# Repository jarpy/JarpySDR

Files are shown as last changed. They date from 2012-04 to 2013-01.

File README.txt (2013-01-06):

JarpySDR - A Tayloe Detector board for Software Defined Radio.

This is a simple SDR frontend using all through-hole components.

It requires an off-board square-wave oscillator/clock running at F*4, where F is the radio frequency to be recieved. The design is pin compatible with WA6UFQ's Si570 oscillator card, and provides an I2C pass-through header with which to program the Si570.

You don't have to use the Si570 board however. You can clock it with any square-wave source you have handy.

The design is derived from the G0NQE Acorn SDR receiver.

Links:
  Si570 oscillator board
  http://home.roadrunner.com/~wa6ufq/universal_vfo_controller.html

  G0NQE Acorn SDR
  http://www.g0nqe.co.uk/projects/g0nqe-acorn_sdr_receiver

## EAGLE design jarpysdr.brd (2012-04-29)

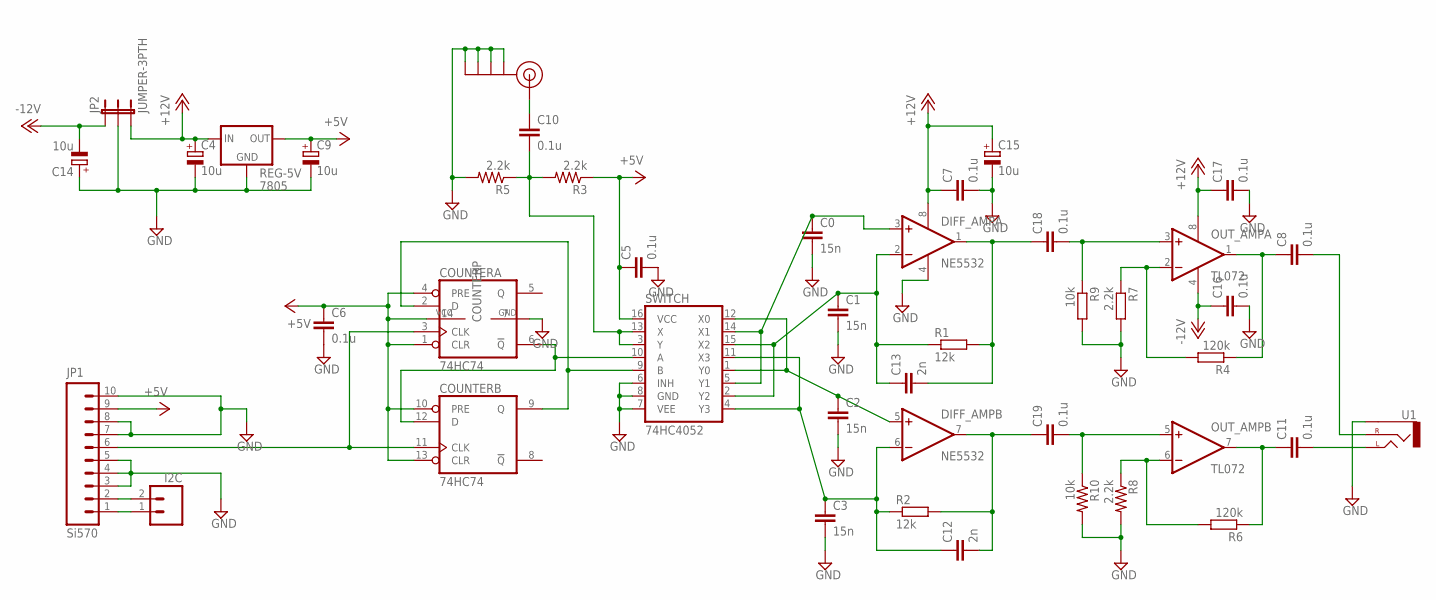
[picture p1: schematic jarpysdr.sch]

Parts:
ANTENNA: SMA_EDGE; SMA-EDGE
C0, C1, C2, C3: 15n; C025-024X044
C4, C9, C14, C15: 10u; E2,5-6
C5, C6, C7, C16, C17: 0.1u; C025-025X050
C8, C11, C18, C19: 0.1u; C050-025X075
C10: 0.1u; C025-024X044
C12, C13: 2n; C025-024X044
COUNTER: 74HC74; DIL14
DIFF_AMP: NE5532; DIL08
I2C: M02PTH; 1X02
JP1: Si570; 1X10
JP2: JUMPER-3PTH; 1X03
OUT_AMP: TL072; DIL08
R1, R2: 12k; 0204/7
R3, R5, R7, R8: 2.2k; 0204/7
R4, R6: 120k; 0204/7
R9, R10: 10k; 0204/7
REG-5V: 7805; 78XXS
SWITCH: 74HC4052; DIL16
U1: AUDIO-JACKPTH; AUDIO-JACK

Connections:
+5V: C5.1, C6.1, C9.+, COUNTER.1 (CLR), COUNTER.4 (PRE), COUNTER.10 (PRE), COUNTER.13 (CLR), COUNTER.14 (VCC), JP1.9, R3.1, REG-5V.OUT, SWITCH.16 (VCC)
+12V: C4.+, C7.1, C15.+, C17.1, DIFF_AMP.8 (V+), JP2.3, OUT_AMP.8 (V+), REG-5V.IN
-12V: C14.-, C16.1, JP2.1, OUT_AMP.4 (V-)
C-180DEG: C1.1, C13.1, DIFF_AMP.2 (-IN), R1.1, SWITCH.2 (Y2), SWITCH.15 (X2)
CLK: COUNTER.3 (CLK), COUNTER.11 (CLK), JP1.6
GND: ANTENNA.GND@0 (GND), ANTENNA.GND@1 (GND), ANTENNA.GND@2 (GND), ANTENNA.GND@3 (GND), C0.2, C1.2, C2.2, C3.2, C4.-, C5.2, C6.2, C7.2, C9.-, C14.+, C15.-, C16.2, C17.2, COUNTER.7 (GND), DIFF_AMP.4 (V-), JP1.3, JP1.4, JP1.5, JP1.7, JP1.8, JP1.10, JP2.2, R5.2, R7.2, R8.2, R9.2, R10.2, REG-5V.GND, SWITCH.6 (INH), SWITCH.7 (VEE), SWITCH.8 (GND), U1.SLEEVE
unnamed: C2.1, DIFF_AMP.5 (+IN), SWITCH.1 (Y0), SWITCH.12 (X0)
unnamed: COUNTER.2 (D), COUNTER.9 (Q), SWITCH.9 (B)
unnamed: COUNTER.6 (!Q), COUNTER.12 (D), SWITCH.10 (A)
unnamed: C10.2, R3.2, R5.1, SWITCH.3 (Y), SWITCH.13 (X)
unnamed: C0.1, DIFF_AMP.3 (+IN), SWITCH.5 (Y1), SWITCH.14 (X1)
unnamed: C13.2, C18.1, DIFF_AMP.1 (OUT), R1.2
unnamed: ANTENNA.SIG (SIGNAL), C10.1
unnamed: C11.2, U1.TIP (LEFT)
unnamed: C8.2, U1.RING (RIGHT)
unnamed: C12.2, C19.1, DIFF_AMP.7 (OUT), R2.2
unnamed: C8.1, OUT_AMP.1 (OUT), R4.1
unnamed: OUT_AMP.2 (-IN), R4.2, R7.1
unnamed: C11.1, OUT_AMP.7 (OUT), R6.1
unnamed: C3.1, C12.1, DIFF_AMP.6 (-IN), R2.1, SWITCH.4 (Y3), SWITCH.11 (X3)
unnamed: OUT_AMP.6 (-IN), R6.2, R8.1
unnamed: I2C.1, JP1.1
unnamed: I2C.2, JP1.2
unnamed: C18.2, OUT_AMP.3 (+IN), R9.1
unnamed: C19.2, OUT_AMP.5 (+IN), R10.1

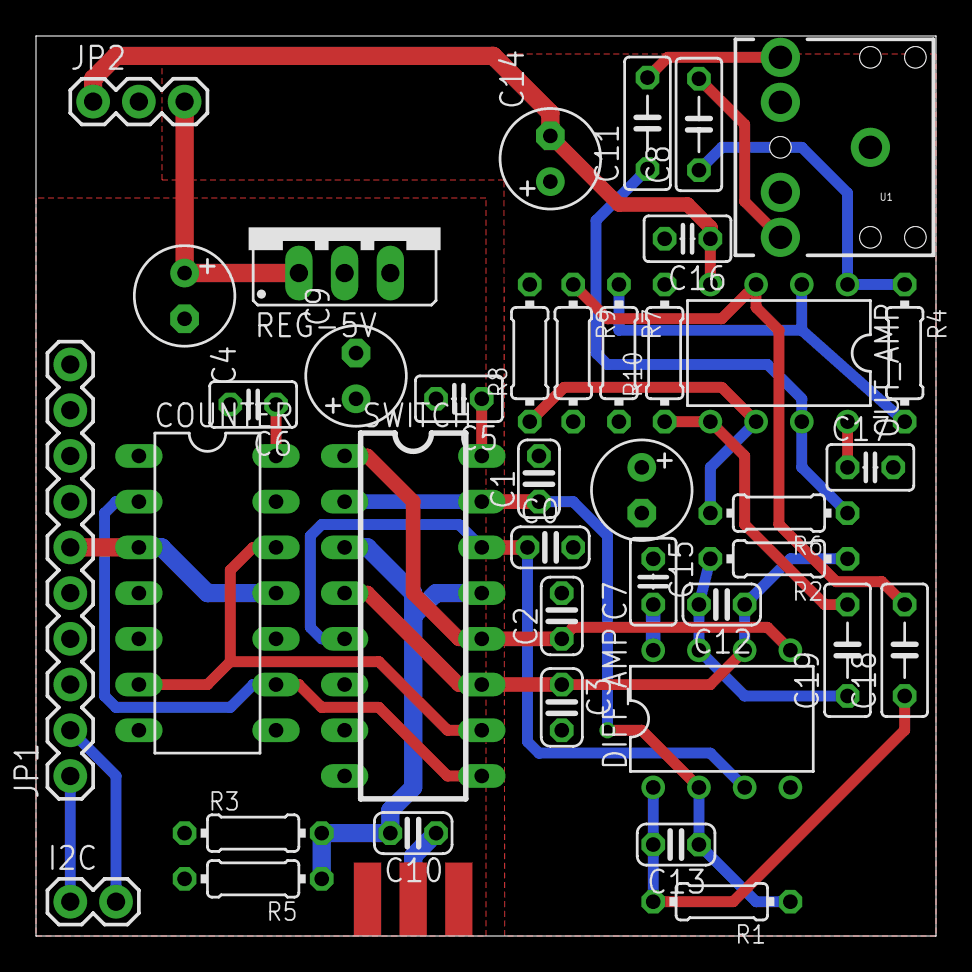
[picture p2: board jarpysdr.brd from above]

Board: 2 copper layers, 50.0 x 50.0 mm, 40 parts (0 on the bottom side), 25 nets.

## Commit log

2011-10-29 First prototype.
    [jarpysdr.brd, jarpysdr.sch]
2012-03-24 - Replace with audio and antenna connectors with jacks available from SparkFun.
    - Make room for a heatsink on the 7805 regulator.
    - Move oscillator daughter-board connecter to edge. (Use right-angle
    female header).
    [jarpysdr.brd, jarpysdr.sch]
2012-03-24 Re-align all parts to a 0.1inch grid.
    [jarpysdr.brd]
2012-03-24 Double-sided layout.
    [jarpysdr.brd, jarpysdr.sch]
2012-03-24 Move osc connector to left edge.
    [jarpysdr.brd]
2012-03-24 Gave some love to the ground plane.
    [jarpysdr.brd]
2012-03-24 Added power planes.
    [jarpysdr.brd]
2012-03-24 Moved drawing to origin.
    [jarpysdr.brd]
2012-03-24 Final physical layout for fab.
    [jarpysdr.brd]
2012-03-24 Set up silkscreen.
    [jarpysdr.brd]
2012-03-24 Release to fab.
    [jarpysdr.brd]
2012-03-24 Really-truly final version for release. Sent to fab. Yay.
    [jarpysdr.brd, jarpysdr.sch]
2012-04-06 AC couple the two opamp stages.
    [jarpysdr.brd, jarpysdr.sch]
2012-04-25 - Increased final stage gain. - Increased bandwidth (smaller sampling capacitors).
    [jarpysdr.brd, jarpysdr.sch]
2012-04-25 Align output jack to board edge.
    [jarpysdr.brd]
2012-04-25 Physical layout for inter-stage AC coupling.
    [jarpysdr.brd, jarpysdr.sch]
2012-04-25 Put NE5532 differential amplifier on a single supply.
    [jarpysdr.brd, jarpysdr.sch]
2012-04-29 New layout. 50x50mm board.
    [jarpysdr.brd, jarpysdr.sch]
